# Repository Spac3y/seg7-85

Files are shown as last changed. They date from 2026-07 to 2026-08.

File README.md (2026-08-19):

# seg7-85

A 4-digit 7-segment display driven by an ATtiny85, scrolling a text message across the display.

## How it works

The ATtiny85 bit-bangs two daisy-chained 74HC595 shift registers to drive a common-anode 4-digit 7-segment display (segments + digit select). A Timer1 CTC interrupt (~3 Hz) shifts the next character of the message into a 4-character rolling buffer, which is refreshed continuously via multiplexing.

Default message: `I LOVE YOU`.

## Hardware (BOM)

| Ref | Part | Qty |
|-----|---|-----|
| U1 | ATtiny85 (DIP-8) | 1 |
| U3, U4 | 74HC595 shift register (DIP-16) | 2 |
| U2 | 4-digit 7-segment display (CC56-12SURKWA) | 1 |
| R1–R4 | 220Ω (segment current limiting) | 4 |
| R5 | 10kΩ (reset pull-up) | 1 |
| C1–C3 | 10µF decoupling | 3 |
| SW1 | Push button (reset/mode) | 1 |
| J1 | 1x06 pin header | 1 |
| J2 | Molex KK-254 1x02 power connector | 1 |

Full BOM: [`kicad/attiny85_7seg.csv`](kicad/attiny85_7seg.csv)

## Repo layout

- `attiny-85_code/attiny-85_code.ino` — firmware (Arduino/AVR)
- `kicad/` — KiCad schematic, PCB layout, and design files
- `kicad/changes.md` — schematic/PCB change log

## Pinout (ATtiny85)

| Pin | Function |
|-----|---|
| PB0 | Shift register data (SER/DS) |
| PB2 | Shift register clock (SRCLK/SHCP) |
| PB3 | Shift register latch (RCLK/STCP) |
| PB4 | Shift register reset (SRCLR/MR) |

## Building/flashing

Flash `attiny-85_code.ino` to the ATtiny85 using the Arduino IDE with an [ATtiny core](https://github.com/SpenceKonde/ATTinyCore) installed, via ISP.

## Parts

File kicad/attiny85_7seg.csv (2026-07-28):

Id | Designator | Footprint | Quantity | Designation | Supplier and ref
1 | C1, C2, C3 | C_Disc_D10.0mm_W2.5mm_P5.00mm | 3 | 10uF
2 | GND1, VCC1 | TestPoint_THTPad_3.0x3.0mm_Drill1.5mm | 2 | TestPoint
3 | J1 | PinHeader_1x06_P2.54mm_Vertical | 1 | Conn_01x06_Pin
4 | J2 | Molex_KK-254_AE-6410-02A_1x02_P2.54mm_Vertical | 1 | Conn_01x02_Pin
5 | R1, R2, R3, R4 | R_Axial_DIN0207_L6.3mm_D2.5mm_P10.16mm_Horizontal | 4 | 220
6 | R5 | R_Axial_DIN0207_L6.3mm_D2.5mm_P10.16mm_Horizontal | 1 | 10k
7 | SW1 | SW_PUSH_6mm | 1 | SW_Push
8 | U1 | DIP-8_W7.62mm | 1 | ATtiny85
9 | U2 | CA56-12SURKWA | 1 | CC56-12SURKWA
10 | U3, U4 | DIP-16_W7.62mm | 2 | 74HC595

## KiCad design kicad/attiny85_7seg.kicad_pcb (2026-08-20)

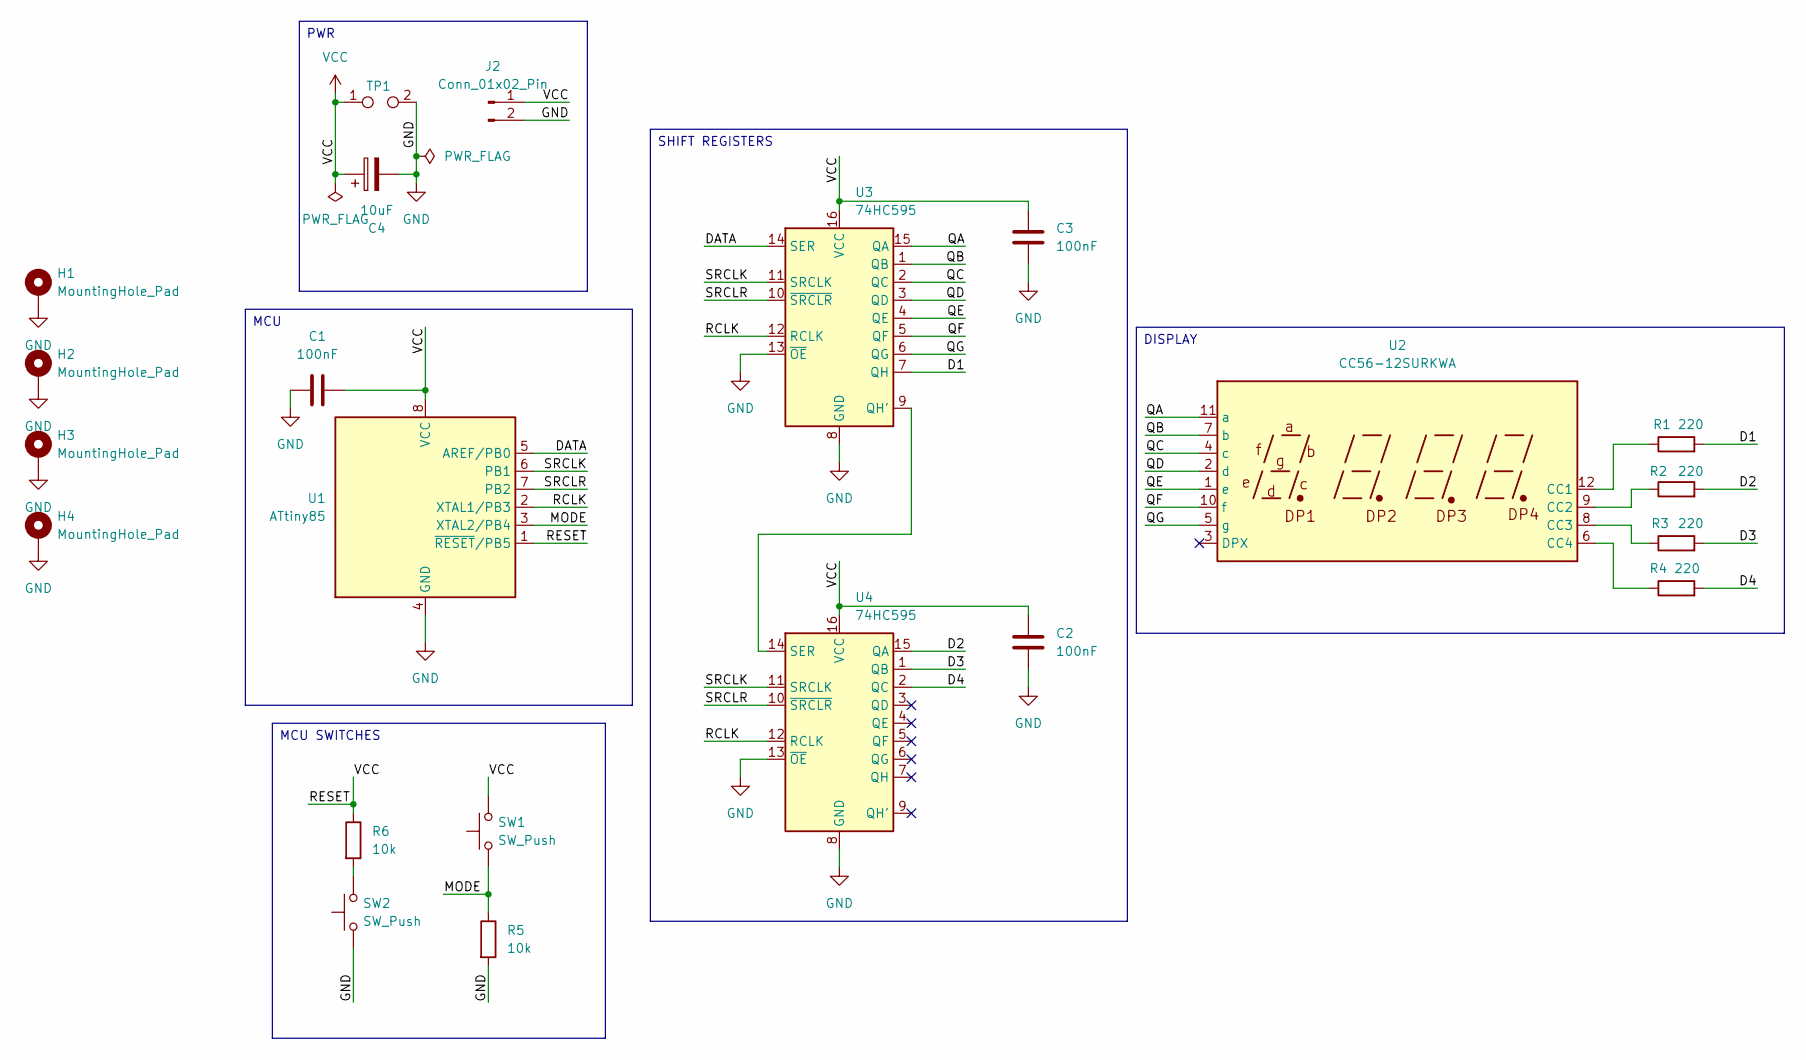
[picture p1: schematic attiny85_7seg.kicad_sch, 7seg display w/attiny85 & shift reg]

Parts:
C1, C2, C3: 100nF; C_Disc_D10.0mm_W2.5mm_P5.00mm
C4: 10uF; CP_Radial_D5.0mm_P2.50mm
H1, H2, H3, H4: MountingHole_Pad; MountingHole_2.7mm_M2.5_DIN965_Pad_TopBottom
J2: Conn_01x02_Pin; Molex_KK-254_AE-6410-02A_1x02_P2.54mm_Vertical
R1, R2, R3, R4: 220; R_Axial_DIN0207_L6.3mm_D2.5mm_P10.16mm_Horizontal
R5, R6: 10k; R_Axial_DIN0207_L6.3mm_D2.5mm_P10.16mm_Horizontal
SW1, SW2: SW_Push; SW_PUSH_6mm
TP1: TestPoint_2Pole; TestPoint_2Pads_Pitch2.54mm_Drill0.8mm
U1: ATtiny85; DIP-8_W7.62mm
U2: CC56-12SURKWA; CA56-12SURKWA
U3, U4: 74HC595; DIP-16_W7.62mm

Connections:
/D1: R1.2, U3.7 (QH)
/D2: R2.2, U4.15 (QA)
/D3: R3.2, U4.1 (QB)
/D4: R4.2, U4.2 (QC)
/DATA: U1.5 (AREF/PB0), U3.14 (SER)
/MODE: R5.1, SW1.1, U1.3 (XTAL2/PB4)
/QA: U2.11 (a), U3.15 (QA)
/QB: U2.7 (b), U3.1 (QB)
/QC: U2.4 (c), U3.2 (QC)
/QD: U2.2 (d), U3.3 (QD)
/QE: U2.1 (e), U3.4 (QE)
/QF: U2.10 (f), U3.5 (QF)
/QG: U2.5 (g), U3.6 (QG)
/RCLK: U1.2 (XTAL1/PB3), U3.12 (RCLK), U4.12 (RCLK)
/SRCLK: U1.6 (PB1), U3.11 (SRCLK), U4.11 (SRCLK)
/SRCLR: U1.7 (PB2), U3.10 (~SRCLR), U4.10 (~SRCLR)
GND: C1.1, C2.2, C3.2, C4.2, H1.1 (1_1), H2.1 (1_1), H3.1 (1_1), H4.1 (1_1), J2.2, R5.2, SW2.1, TP1.2, U1.4 (GND), U3.8 (GND), U3.13 (~OE), U4.8 (GND), U4.13 (~OE)
unnamed: R6.2, SW2.2
unnamed: R1.1, U2.12 (CC1)
unnamed: R2.1, U2.9 (CC2)
unnamed: R3.1, U2.8 (CC3)
unnamed: R4.1, U2.6 (CC4)
unnamed: U3.9 (QH'), U4.14 (SER)
VCC: C1.2, C2.1, C3.1, C4.1, J2.1, R6.1, SW1.2, TP1.1, U1.1 (~RESET/PB5), U1.8 (VCC), U3.16 (VCC), U4.16 (VCC)

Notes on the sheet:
SHIFT REGISTERS
DISPLAY
PWR
MCU
MCU SWITCHES

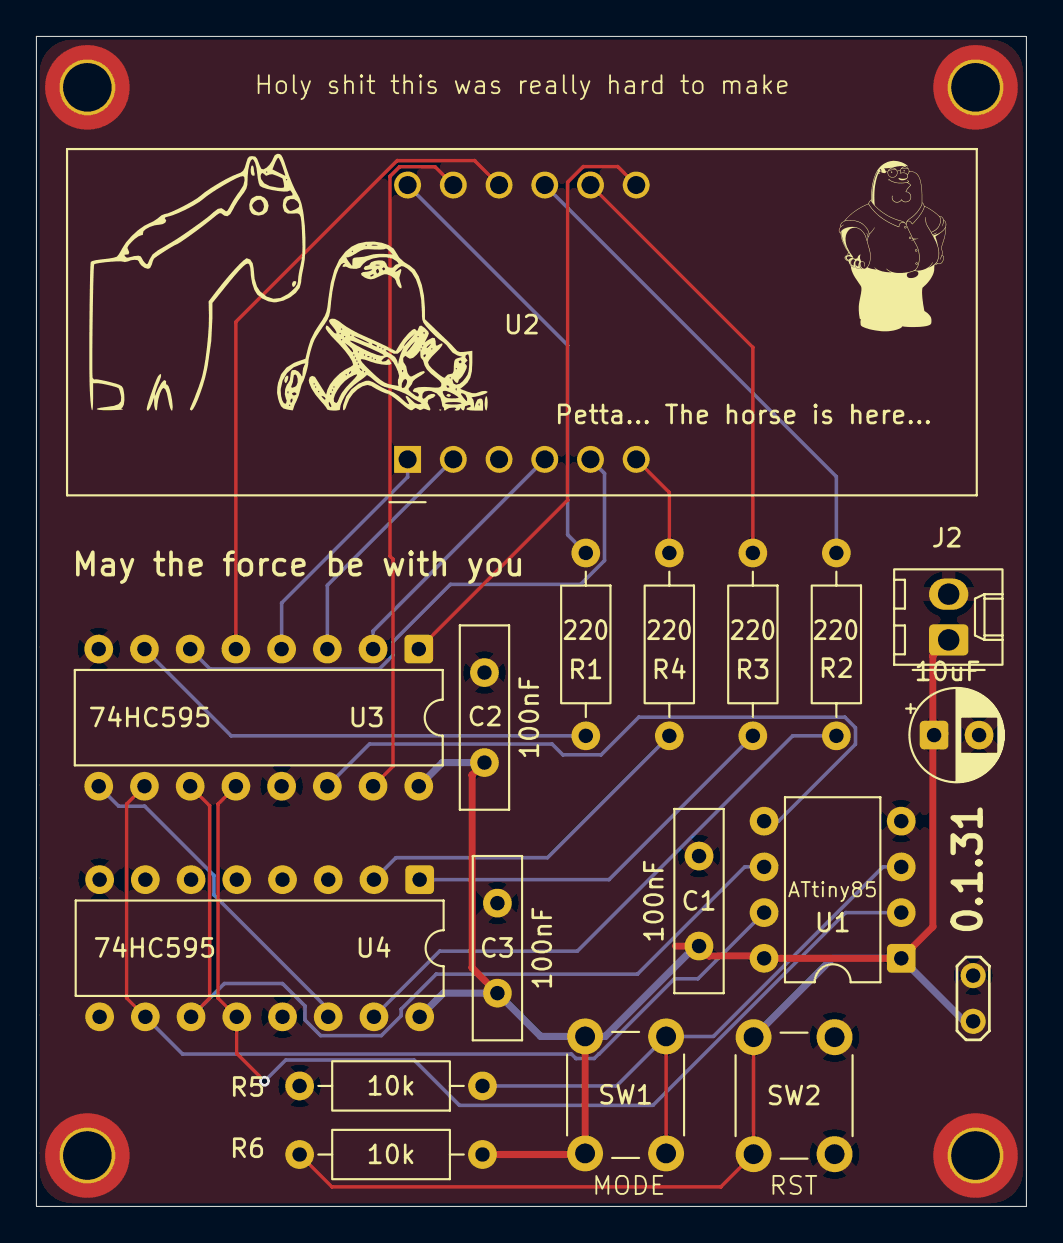
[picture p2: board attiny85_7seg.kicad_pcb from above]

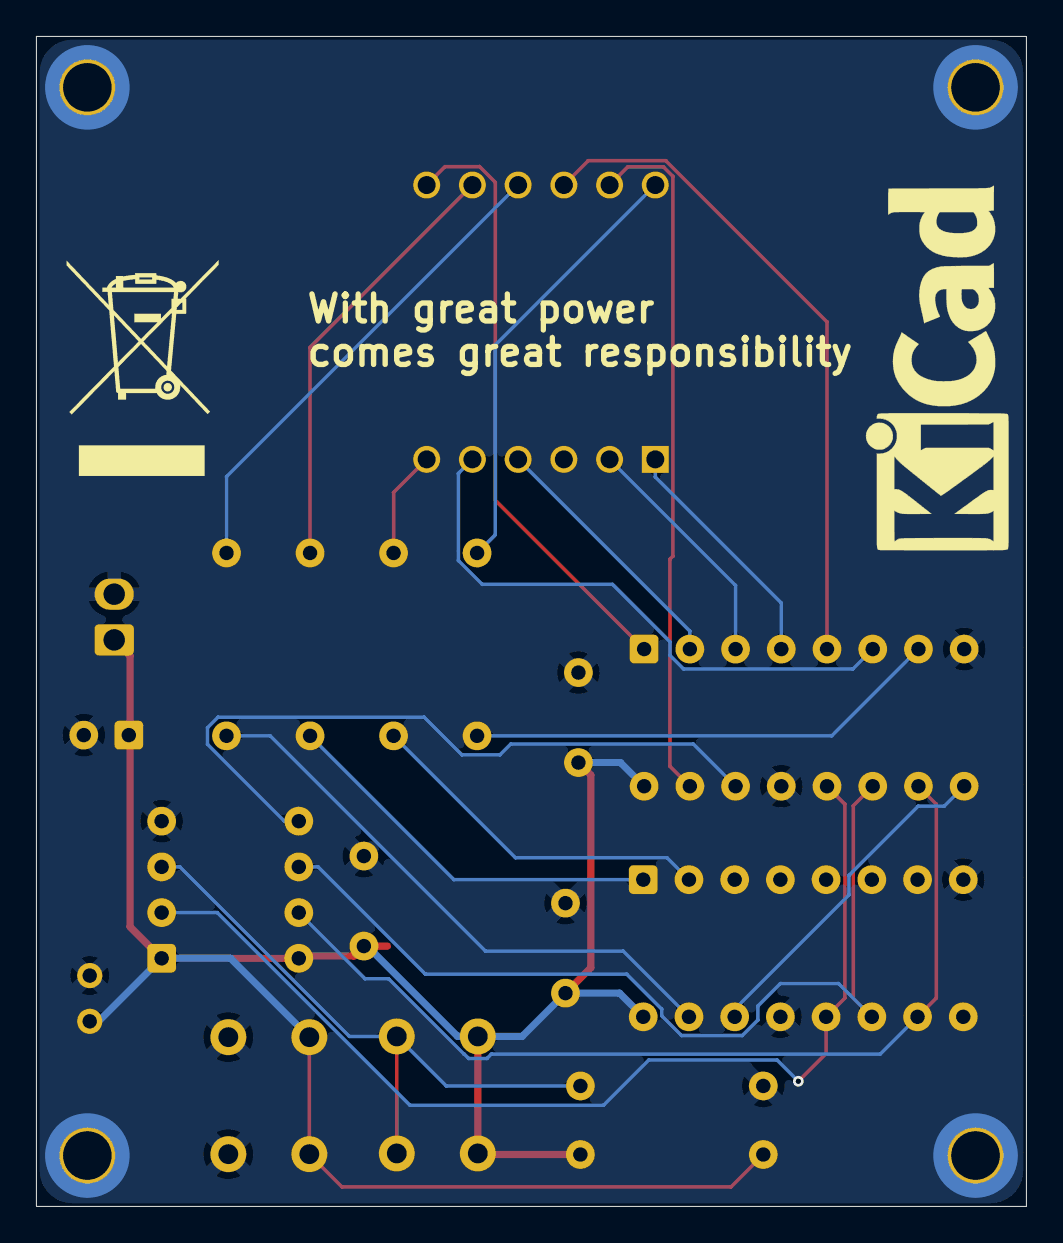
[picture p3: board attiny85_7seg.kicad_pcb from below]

Board: 2 copper layers, 55.0 x 65.0 mm, 26 parts (2 on the bottom side), 24 nets.

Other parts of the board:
IMG1: LOGO; Peter_Image
IMG2: KiCad-Logo_8mm_SilkScreen
IMG3: WEEE-Logo_8.4x12mm_SilkScreen
LOGO1: LOGO; thehorseishere

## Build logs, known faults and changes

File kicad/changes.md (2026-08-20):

# Change log
This file keeps track of changes/updates on schematic and pcb design

--v0.1.31:__
- Added dimensions for 3D printing on User1 layer

__v0.1.3:__
- Fix reset PullUp button

__v0.1.2:__
- Fix bulk capacitor polarity

__v0.1.1:__
- Change mounting hole type to mounting pad and connected it to GND

__v0.1.0:__
- Change footprint of power connector
	(pinHeader 2.54mm -> Molex KK-254 2.54mm)
- Increase size of board 61mm -> 65mm
- Add explicit text for reset & mode buttons 
- Add decoupling electrolytic cap to main power rail
- Add programmable + reset buttons for Attiny85
- Change testpoints footprint

__v0.0.6:__
- Add decoupling capacitors to ICs

__v0.0.5:__
- Add push button to PB4 pin

__v0.0.4:__
- Add image on b.silkscreen
- change routing using plugin

__v0.0.3:__
- Fix text orientation for components-F.silkscreen
- Change testpoint footprints
- Add text-F.silkscreen

__v0.0.2:__
- Fix pin headers footprint 1mm -> 2.54mm

__v0.0.1:__
- initial design

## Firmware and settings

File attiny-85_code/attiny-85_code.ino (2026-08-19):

#define DATA_PIN   0   // PB0 - SER   (DS)
#define CLOCK_PIN  1   // PB2 - SRCLK (SHCP)  ← moved from PB1
#define RESET_PIN  2   // PB4 - SRCLR (MR)    ← moved from PB3
#define LATCH_PIN  3   // PB3 - RCLK  (STCP)  ← moved from PB2

// ATtiny85 Timer1: 8-bit, prescaler /16384
// 8MHz / 16384 / 162 ≈ 3 Hz scroll rate
#define TIMER1_TOP 162

const size_t segLen = 7;
const size_t digitsLen = 4;

const char keys[] = {'I', 'L', 'O', 'V', 'E', 'Y', 'U', 'H',' ', '-'};
const uint8_t values[] = { 0b0000110, 0b0001110, 0b1111110, 0b0111110, 0b1001111, 0b0110011, 0b0111110, 0b0110111, 0b0000000, 0b0000001 };
const uint8_t MAP_SIZE =  10;


const char message[] = "I LOVE YOU   ";
const uint16_t length = sizeof(message)/sizeof(message[0]);

volatile unsigned ind = 0;
volatile char buffer[4] = { ' ', ' ', ' ', ' ' };
                            /* 3    2    1    0*/
volatile bool doShift = false;

uint8_t getMapValue(char key) {
  for(uint8_t i = 0; i < MAP_SIZE; i++) 
    if(keys[i] == key)
      return values[i];
  return 0;
}

void resetShiftRegister() {
  digitalWrite(RESET_PIN, LOW);
  delayMicroseconds(1);
  digitalWrite(RESET_PIN, HIGH);
}

void latchOutput() {
  digitalWrite(LATCH_PIN, HIGH);
  delayMicroseconds(1);
  digitalWrite(LATCH_PIN, LOW);
}

uint16_t combineData(uint8_t data, uint8_t poz) {
  poz = ~(1 << poz);
  uint16_t rez = ((uint16_t)(data & 0x7F) << 4) | (poz & 0x0F);
  return rez;
}

void writeShiftRegister(uint8_t data, uint8_t poz) {
  // 1. Clear shift register before writing
  resetShiftRegister();

  uint16_t value = combineData(data, poz);

  // 2. Clock out 11 bits, MSB first
  for (int8_t bit = 0; bit < 11; bit++) {
    digitalWrite(DATA_PIN,  (value >> bit) & 0x01);
    digitalWrite(CLOCK_PIN, HIGH);
    delayMicroseconds(1);
    digitalWrite(CLOCK_PIN, LOW);
  }

  // 3. Transfer shift register → output latches
  latchOutput();
}

void displayBuffer() {
  for (unsigned i = 0; i < 4; i++) {
    writeShiftRegister(getMapValue(buffer[i]), 3-i);
    delay(2);
  }
}

void shiftLetter(char letter) {
  for (unsigned i = 1; i < 4; i++) {
    buffer[i - 1] = buffer[i];
  }
  buffer[3] = letter;
}

ISR(TIMER1_COMPA_vect) {
  doShift = true;
}

void startAnimation() {
  const unsigned time = 125;

  for(short i = 0; i < 7; i++) {
    uint8_t data = ~(1 << i) & 0x7F;
    for(short j = 0; j < 4; j++) {
      writeShiftRegister(data, j);
      delay(2);
    }
    delay(time);
  }

  for(short i = 0; i < 3; i++) {
    for(short j = 0; j < 4; j++) {
      writeShiftRegister(getMapValue('-'), j);
      delay(2);
    }
    delay(time);

    for(short j = 0; j < 4; j++) {
      writeShiftRegister(getMapValue(' '), j);
      delay(2);
    }
  }
}

void setup() {

  pinMode(DATA_PIN, OUTPUT);
  pinMode(CLOCK_PIN, OUTPUT);
  pinMode(LATCH_PIN, OUTPUT);
  pinMode(RESET_PIN, OUTPUT);

  resetShiftRegister();

  // startAnimation();

  cli();
  TCCR1 = 0;
  GTCCR = 0;
  TCNT1 = 0;
  OCR1C = TIMER1_TOP;             // TOP for CTC mode
  OCR1A = TIMER1_TOP;             // compare match A = fire ISR at TOP
  TCCR1 |= (1 << CTC1);          // CTC mode (clear on OCR1C match)
  TCCR1 |= 0x0F;                  // prescaler /16384 (CS13:CS10 = 1111)
  TIMSK |= (1 << OCIE1A);         // enable compare match A interrupt
  sei();
}

void loop() {
  if(doShift) {
    doShift = false;
    shiftLetter(message[ind]);
    ind = (ind+1) % length;
  }
  displayBuffer();
}

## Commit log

2026-08-19 Move kicad files into kicad/ folder
    [attiny85_7seg.csv, attiny85_7seg.dsn, attiny85_7seg.kicad_pcb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]
2026-09-08 Add schematic photo to readme
2026-10-25 update schematic photo && gitignore
